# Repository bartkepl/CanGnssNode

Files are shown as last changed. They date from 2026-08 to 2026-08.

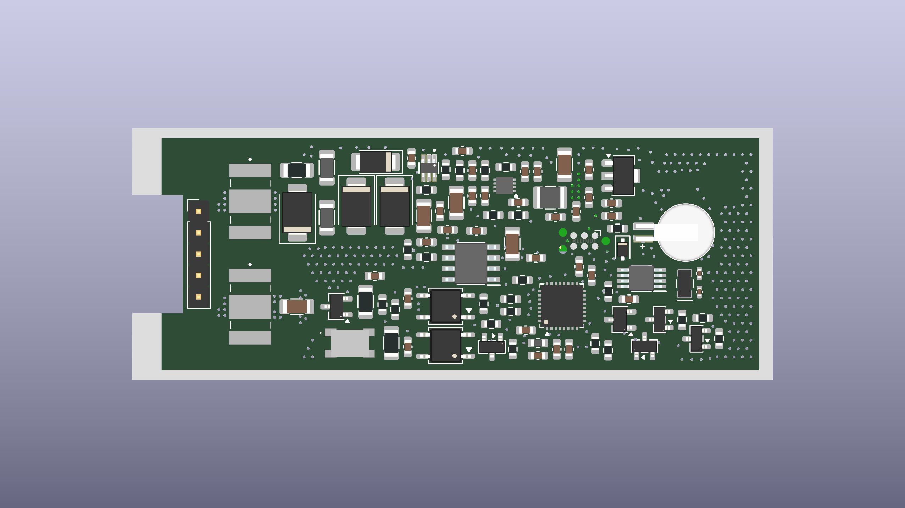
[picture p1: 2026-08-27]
media/gnss_node_front.png

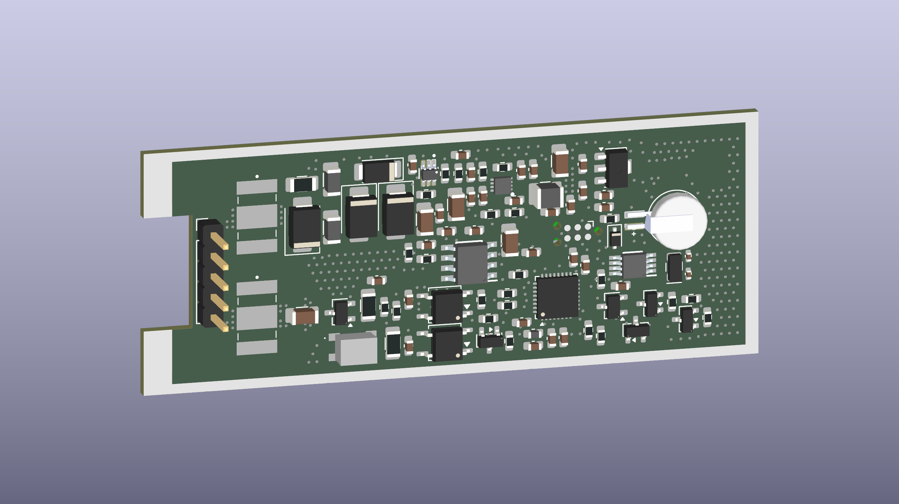
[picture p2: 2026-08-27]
media/gnss_node_angle.png

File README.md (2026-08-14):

# CanGnssNode
## Odbiornik GNSS z interfejsem CAN

Polowy węzeł pozycyjny z modułem GNSS **Quectel L76-L** (GPS/GLONASS/Galileo/QZSS), komunikujący się cyfrowo przez **CAN 2.0B**. Zaprojektowany jako element rozproszonego systemu pomiarowego: wąski cylindryczny węzeł w obudowie aluminiowej, jedno złącze M12, micropower, odporność EMC klasy przemysłowej.







> **Status:** ta sama filozofia konstrukcyjna co u poprzedniej rewizji sprzętu (rura aluminiowa, złącze M12, zasilanie/CAN/RTC bez zmian), ale sonda pomiarowa i obwód wysokiego napięcia zostają zastąpione modułem GNSS. Elektronika (schemat, PCB) jest obecnie przebudowywana w KiCad — patrz [TODO_GPS_CONVERSION.md](TODO_GPS_CONVERSION.md) po aktualny stan prac i listę zmian do wprowadzenia. Firmware na etapie szkieletu bring-up.

---

## Płytka

PCB będzie **mniejsze i dwustronne** względem pierwowzoru: jedna strona elektronika cyfrowa/zasilanie, druga strona w całości zarezerwowana pod tor RF/antenę GNSS — dzięki temu moduł L76-L może leżeć blisko krawędzi płytki, która trafia pod plastikowy insert z anteną (patrz [Mechanika](#mechanika)). Finalne wymiary i layout są w toku (KiCad) — renderów jeszcze nie ma; zostaną wygenerowane jobsetem [gen_media.kicad_jobset](pcb/gen_media.kicad_jobset) po dokończeniu PCB.

---

## Najważniejsze cechy

- **Prosty odbiornik pozycji GNSS** — moduł Quectel L76-L (GPS + GLONASS + Galileo + QZSS, 33 kanały śledzenia), dane NMEA po UART, pozycja wysyłana cyklicznie na CAN.
- **Micropower** — pobór idle rzędu setek µA dzięki buckowi LT8606 (Iq 2.5 µA) i MCU w trybie niskiego poboru (do ustalenia docelowy tryb w firmware — L76-L ma własne tryby Periodic/AlwaysLocate™/Standby/Backup do wykorzystania).
- **CAN 2.0B (29-bit ID)** z wybudzaniem na aktywność magistrali, 125 kbit/s – 1 Mbit/s.
- **Przełączalna terminacja CAN** — split 2×59 Ω + 4.7 nF załączany dwoma PhotoMOS-ami z GPIO (węzeł na końcu linii vs. w środku, bez zwór).
- **Pomiar własnego poboru prądu** — INA186 A4 (G=200) + shunt 0.5 Ω, rozdzielczość ~2 µA/count; diagnostyka linii i weryfikacja budżetu mocy.
- **Zegar czasu rzeczywistego z podtrzymaniem** — MCP79410 + ogniwo MS621FE; kwarc 32.768 kHz służy też do kalibracji wewnętrznego MSI w STM32. Docelowo RTC dostaje korektę z czasu UTC dostarczanego przez GNSS po uzyskaniu fixa.
- **Odporność EMC** — kaskadowa ochrona coarse→fine (GDT 3-elektrodowe / TVS / CMC / podwójne ferryty) na zasilaniu i CAN, testy IEC 61000-4-2/-4/-5.
- **Obudowa aluminiowa IP67**, złącze M12 5-pin A-coded (standard CANopen CiA 303-1).

---

## Specyfikacja

| Parametr | Wartość |
|---|---|
| Moduł GNSS | Quectel L76-L (LCC-18, 10.1×9.7×2.5 mm) |
| Konstelacje | GPS, GLONASS, Galileo (E1), QZSS, SBAS (WAAS/EGNOS/MSAS/GAGAN) |
| Dokładność pozycji | < 2.5 m CEP (autonomicznie) |
| TTFF | ~5 s (warm start, EASY™) |
| Czułość | -167 dBm (tracking) / -149 dBm (acquisition) |
| Wyjście danych | NMEA 0183 po UART, domyślnie 9600 8N1 (opcjonalnie I2C — L76-L ma wyprowadzone I2C_SDA/SCL) |
| Interfejs magistrali | CAN 2.0B (extended ID), 125k / 250k / 500k / 1 Mbit |
| Zasilanie | 7–32 V DC, wspólna masa (bez izolacji galwanicznej) |
| Ochrona EMC | ESD ±8 kV, Burst ±2 kV, Surge ±2 kV |
| Złącze | M12 5-pin A-coded (1=Vin, 2=GND, 3=CAN_H, 4=CAN_L, 5=Earth) |
| PCB | dwustronne, wymiary w trakcie ustalania (KiCad) |
| Obudowa | Aluminiowa cylindryczna, rura **32×1 mm** (Ø wewn. ≈ 30 mm), z uchwytem mocującym; górna część = insert plastikowy z miejscem na antenę GNSS |

---

## Architektura

```
M12 Vin (7-32V) ─▶ Ochrona (GDT+TVS+ferryt) ─▶ shunt 0.5Ω ─▶ LT8606 buck ─▶ +5V ─┬─▶ ATA6561 (CAN)
                                                    │                              │
                                                 INA186 ─▶ ADC                     ├─▶ MCP1700 LDO ─▶ +3.3V ─┬─▶ STM32L432
                                                                                   │                          │
                                                                                   │                MCP79410 RTC + BT1
                                                                                   │                          │
                                                                                   └──────────────────────────┴─▶ Quectel L76-L ─▶ antena GNSS
                                                                                                                          │
                                                                                                    UART (NMEA) ──────────┘
                                                                                                          │
                                                                                                    STM32L432 ─▶ parsowanie ─▶ ramki CAN z pozycją
```

Kluczowa cecha: **wspólna masa** (star ground), izolacja zapewniona wyłącznie przez TVS/GDT; `Earth` (obudowa) oddzielona od `GND` sygnałowej i łączona tylko przez Y-cap 1 nF/2 kV.

### Arkusze schematu

| Arkusz | Plik | Zawartość | Status |
|---|---|---|---|
| root | [gnss_node.kicad_sch](pcb/gnss_node.kicad_sch) | połączenia hierarchiczne | do aktualizacji (patrz TODO) |
| PWR | [pwr.kicad_sch](pcb/pwr.kicad_sch) | buck LT8606, LDO MCP1700, INA186, dzielnik VIN_SENSE | bez zmian — w pełni odziedziczone |
| MCU | [mcu.kicad_sch](pcb/mcu.kicad_sch) | STM32L432, RTC MCP79410, kwarc 32k, SWD (Tag-Connect) | do aktualizacji (piny UART/PPS/RESET do GNSS) |
| GPS | `gps.kicad_sch` (do utworzenia) | moduł Quectel L76-L, antena, VBACKUP | nowy arkusz — patrz TODO |
| CAN_BUS | [can_bus.kicad_sch](pcb/can_bus.kicad_sch) | ATA6561, terminacja PhotoMOS | bez zmian — w pełni odziedziczone |
| PROTECTION | [prot.kicad_sch](pcb/prot.kicad_sch) | ochrona Vin i CAN, złącze M12 | bez zmian — w pełni odziedziczone |
| ~~HV~~ | ~~`hv.kicad_sch`~~ | ~~flyback, dzielnik HV, detektor G-M~~ | **do usunięcia** |

Pełna checklista zmian: [TODO_GPS_CONVERSION.md](TODO_GPS_CONVERSION.md).

---

## Kluczowe komponenty

| Blok | Element | Uwaga |
|---|---|---|
| GNSS | Quectel L76-L | LCC-18, UART NMEA 9600 8N1 (opcjonalnie I2C), VCC 2.8–4.3 V (typ. 3.3 V z istniejącej szyny), V_BCKP z istniejącego BT1 |
| Antena | pasywna lub aktywna GNSS 1575 MHz | pasywna wystarcza przy odległości anteny od modułu < 1 m (nasz przypadek — insert w tej samej rurze); aktywna wymaga zasilania z pinu VDD_RF modułu |
| Buck | LT8606IDC#TRPBF | DFN-8, Iq 2.5 µA (zawsze Burst Mode), Vref FB 0.778 V |
| LDO 3.3 V | MCP1700-3302E/MB | SOT-89, Iq 1.6 µA |
| Current sense | INA186A4IDCKR + 0.5 Ω | 40 V CM, G=200, pin EN — pomiar poboru węzła |
| MCU | STM32L432KCU6 | bxCAN, USART2 (GNSS), I2C1 (RTC) |
| RTC | MCP79410-I/MS + MS621FE-FL11E | RTC/EEPROM I2C z podtrzymaniem, kwarc 32.768 kHz |
| CAN | ATA6561-GAQW-N | zamiennik TJA1042 |
| Terminacja CAN | 2× GAQY212GS + 2× 59 Ω + 4.7 nF | split przełączalny, sterowany BSS138 |
| Ochrona Vin | 3R090-5S (GDT) + SMBJ33CA + PMEG6030EP + 2× SMBJ36A | kaskada coarse→fine, podwójny ferryt BLM31 |
| Ochrona CAN | 3R090-5S + CDSOT23-T24CAN + ACT45B-510 | GDT, dedykowany TVS, CMC |

Pełna lista: `prod/bom/` (generowana z KiCad, nietrackowana w git, do wygenerowania po dokończeniu schematu/PCB).

---

## Ramki CAN — szkic protokołu v1

Firmware jest na etapie szkieletu (peryferia zainicjalizowane, brak logiki aplikacji), więc poniższy format to **zamierzenie do implementacji**, nie działający kod. Trzy ramki standardowe (8 B danych), wysyłane cyklicznie po uzyskaniu fixa:

| Ramka | Zawartość (bajty) |
|---|---|
| `POSITION` | szerokość geogr. (int32, 1e-7°) · długość geogr. (int32, 1e-7°) |
| `ALT_SPEED` | wysokość n.p.m. (int32, mm) · prędkość (uint16, 0.01 m/s) · kurs (uint16, 0.01°) |
| `STATUS_TIME` | czas UTC (uint32, epoch) · jakość fixa (uint8) · liczba satelitów (uint8) · HDOP (uint16, 0.01) |

Identyfikatory CAN, dokładna semantyka pól i częstotliwość nadawania do ustalenia razem z resztą firmware (Faza 4 poniżej).

---

## Mechanika

**Rura aluminiowa 32×1 mm** (Ø wewn. ≈ 30 mm) z uchwytem mocującym, IP67 — ta sama koncepcja montażu co u poprzedniej rewizji sprzętu. Różnica: zamiast górnej części z sondą pomiarową — **plastikowy insert z miejscem na antenę GNSS**, bo aluminium ekranuje sygnał satelitarny i antena musi „widzieć” niebo przez materiał nieprzewodzący. PCB (dwustronne, strona RF skierowana pod insert) oraz szczegóły osadzenia anteny (na płytce vs. pigtail do anteny patch w insercie) są przedmiotem trwającej przebudowy w KiCad.

---

## Firmware

Projekt STM32CubeIDE w [firmware/CanGnssNode/](firmware/CanGnssNode/) — na razie szkielet wygenerowany z CubeMX z inicjalizacją CAN1 i I2C1. Peryferia po dawnej sondzie pomiarowej (ADC HV_meas, COMP1, DAC1, TIM2) czekają na usunięcie, a USART2 do modułu GNSS na dodanie — pełna lista zmian w `.ioc` w [TODO_GPS_CONVERSION.md](TODO_GPS_CONVERSION.md). Logika aplikacji (parsowanie NMEA, budowa i nadawanie ramek CAN) do napisania.

---

## Roadmap

- [x] **Faza 1** — wydzielenie nowego sub-projektu, dobór modułu GNSS (Quectel L76-L), dokumentacja zamierzenia
- [ ] **Faza 2** — przebudowa schematu w KiCad: nowy arkusz GPS, usunięcie arkusza HV, aktualizacja pinów MCU (patrz TODO)
- [ ] **Faza 3** — przebudowa PCB (dwustronne, sekcja RF), pliki produkcyjne
- [ ] **Faza 3b** — zamówienie PCB, montaż, bring-up sprzętowy
- [ ] **Faza 4** — firmware (parser NMEA, protokół CAN z pozycją, synchronizacja RTC z czasem GNSS, tryby oszczędzania energii L76-L)
- [ ] **Faza 5** — testy terenowe (dokładność pozycji, TTFF, zasięg anteny w obudowie), testy EMC
- [ ] **Faza 6** — mechanika: rura Al 32×1 mm, plastikowy insert z anteną, testy IP67

---

## Struktura repozytorium

```
.
├── media/          # rendery 3D płytki (do wygenerowania po nowym PCB)
├── pcb/            # projekt KiCad 10 (schemat hierarchiczny, PCB, biblioteki lokalne, modele 3D)
├── prod/           # pliki produkcyjne: gerbery (.zip), PDF schematu i PCB, interaktywny BOM (do wygenerowania po nowym PCB)
├── sim/            # symulacje LTspice (LT8606 buck)
└── firmware/       # projekt STM32CubeIDE (STM32L432, szkielet bring-up)
```

Pliki produkcyjne generowane są jobsetami KiCad: [gen_prod.kicad_jobset](pcb/gen_prod.kicad_jobset) (PDF + BOM), [gen_gerber.kicad_jobset](pcb/gen_gerber.kicad_jobset) (gerbery + wiertła), [gen_media.kicad_jobset](pcb/gen_media.kicad_jobset) (rendery 3D).

---

## Referencje

- Quectel **L76 & L76-L Hardware Design** (GNSS Module Series), v3.2 — pinout, elektryka, projekt anteny
- NMEA 0183 — format komunikatów wyjściowych GNSS
- STM32L432: RM0394, DS11453; bxCAN: AN2606, AN5028
- LT8606 (Analog Devices), MCP1700 / MCP79410 / ATA6561 (Microchip)
- IEC 61000-4-2/-4/-5; EN 61326-1; EN 61000-6-2
- CAN 2.0B: ISO 11898-1/-2; CANopen CiA 301, CiA 303-1; M12: IEC 61076-2-101

---

## Licencja

MIT

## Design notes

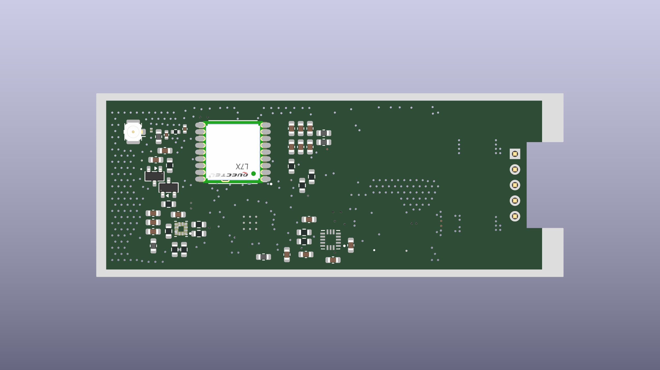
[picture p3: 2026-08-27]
media/gnss_node_back.png

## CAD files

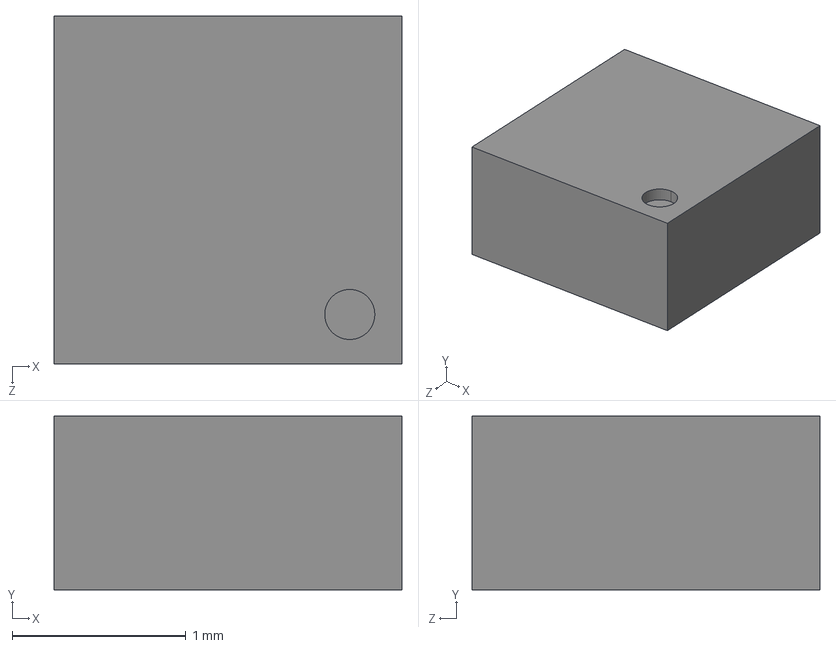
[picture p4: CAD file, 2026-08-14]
pcb/lib_local/LSM303AGR.step
2.00 x 1.00 x 2.00 mm

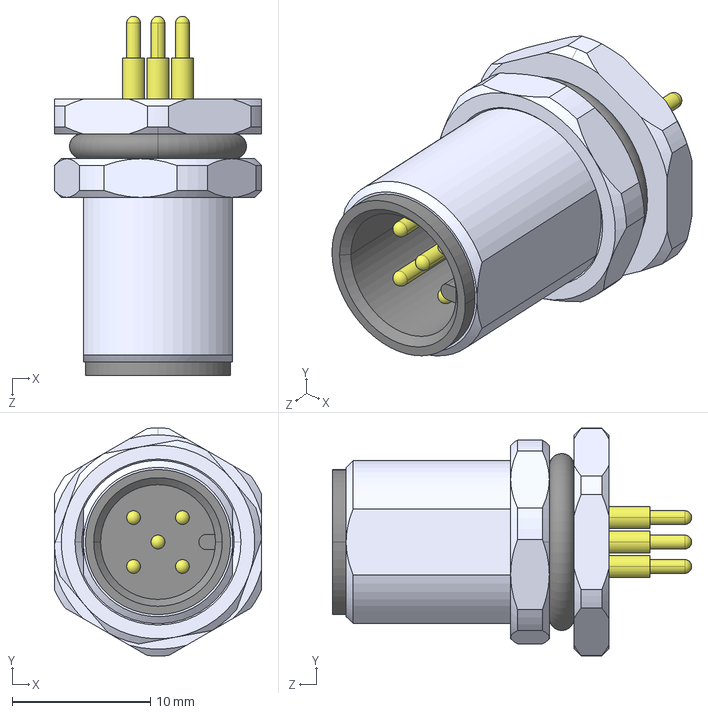
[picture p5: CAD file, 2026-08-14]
pcb/lib_local/CDM1209-05A-MP-F12-67.step
15.0 x 16.5 x 26.0 mm
CDM1209 HOUSING
PINS_MALE_REAR_5P

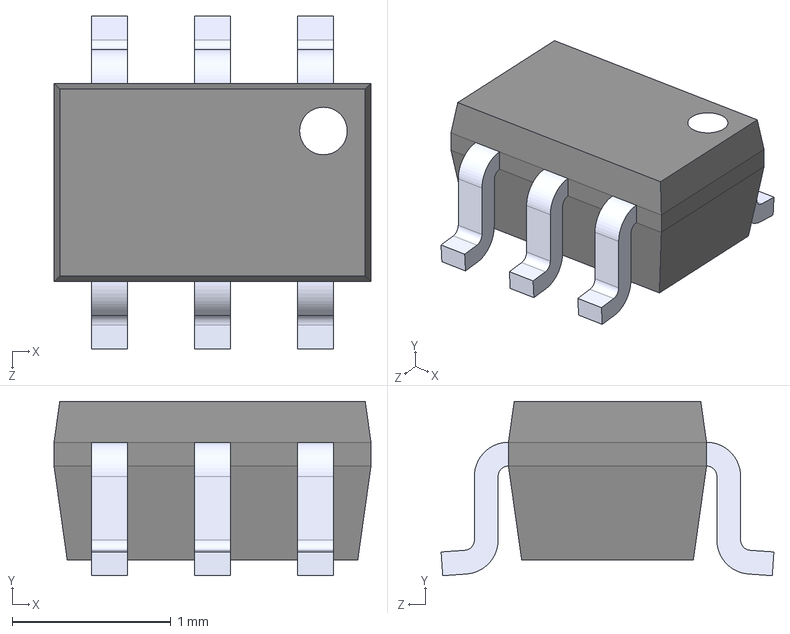
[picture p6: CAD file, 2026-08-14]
pcb/lib_local/INA186A4IDCKR.step
2.00 x 1.10 x 2.10 mm

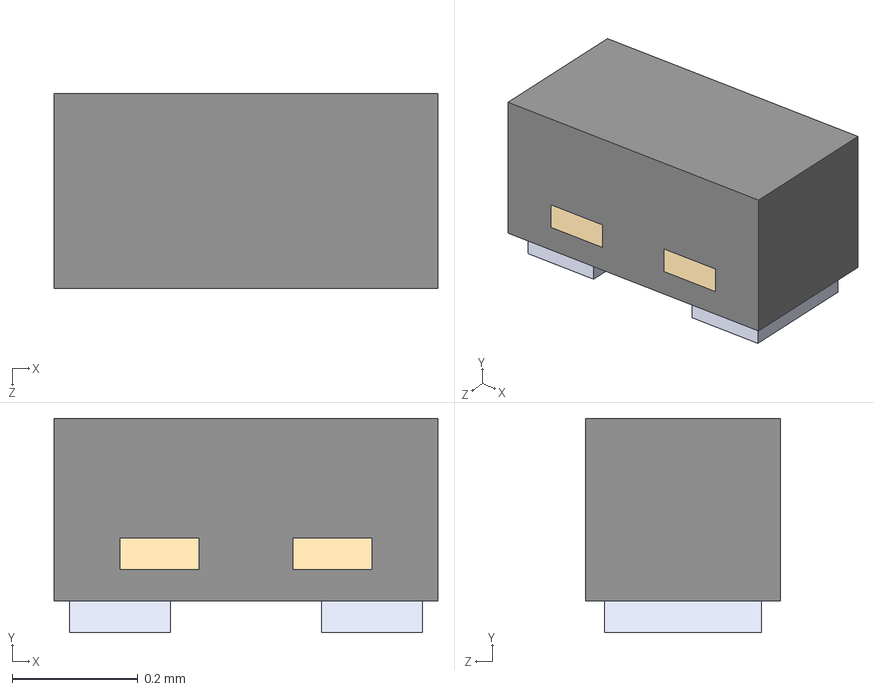
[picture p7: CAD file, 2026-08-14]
pcb/lib_local/DFN0603.step
0.61 x 0.34 x 0.31 mm

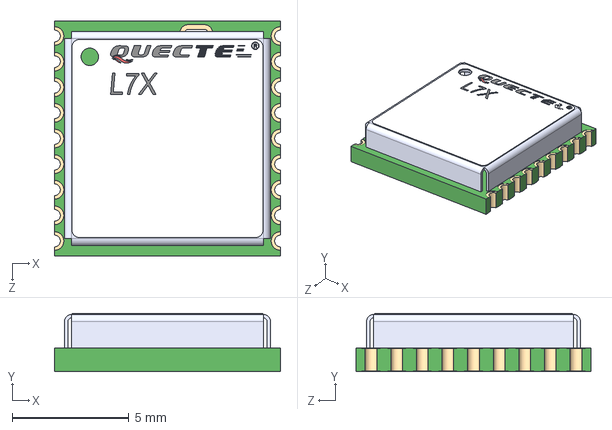
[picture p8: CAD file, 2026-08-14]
pcb/lib_local/L76L-M33.step
9.70 x 2.49 x 10.1 mm

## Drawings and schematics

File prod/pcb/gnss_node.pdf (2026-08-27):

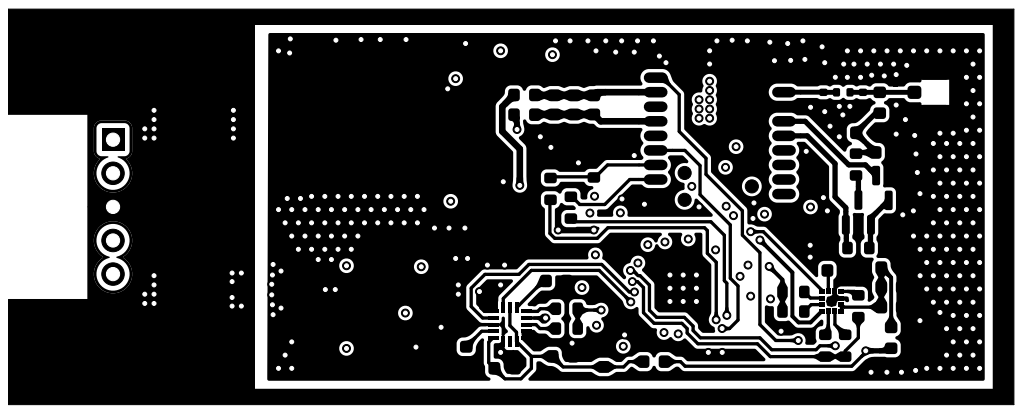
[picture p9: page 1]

Size: A4 | Rev:
KiCad E.D.A. 10.0.4 | Id: 1/6

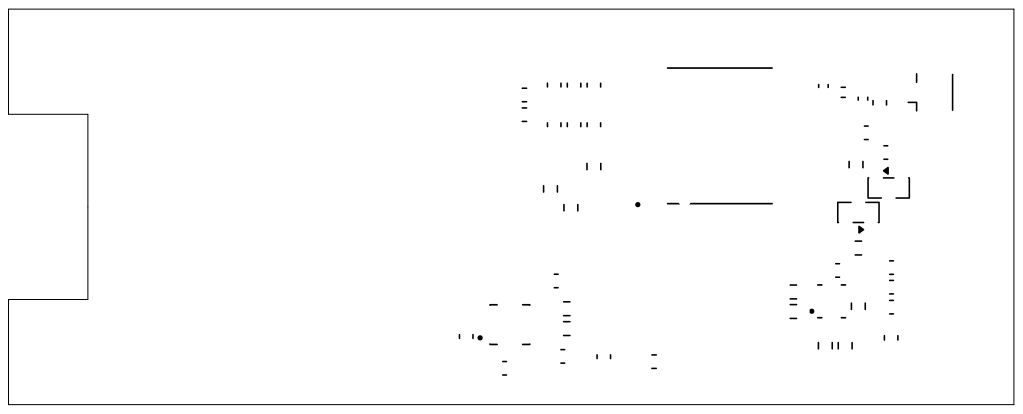
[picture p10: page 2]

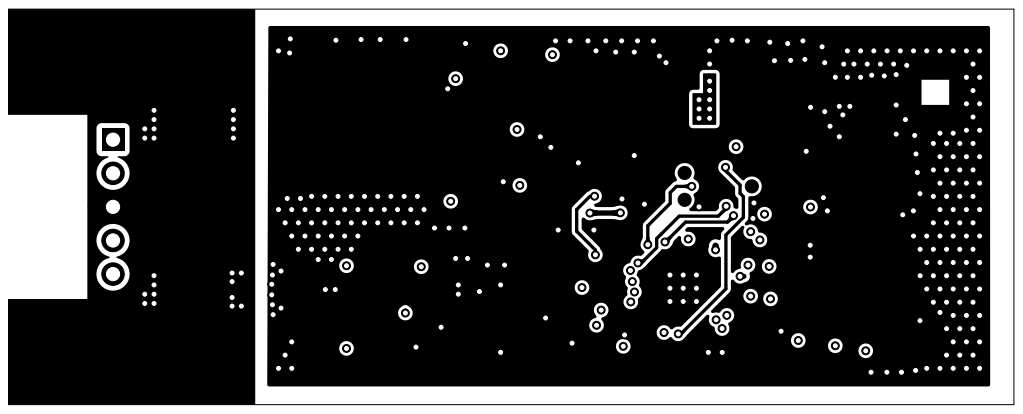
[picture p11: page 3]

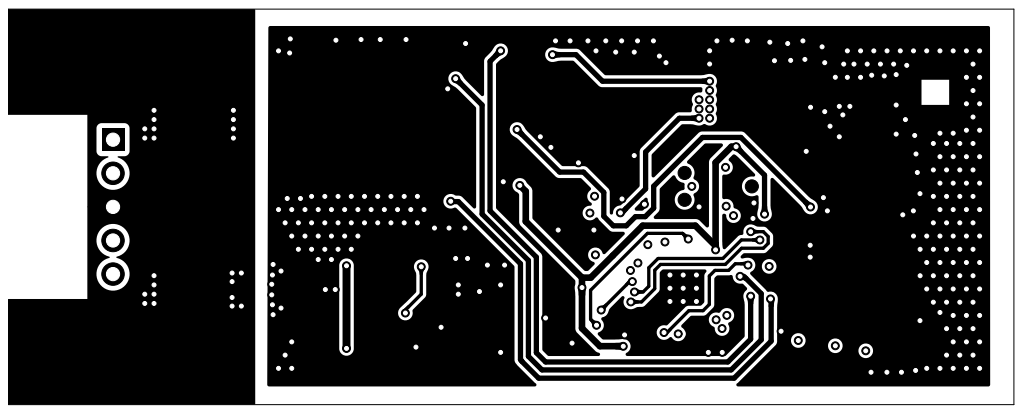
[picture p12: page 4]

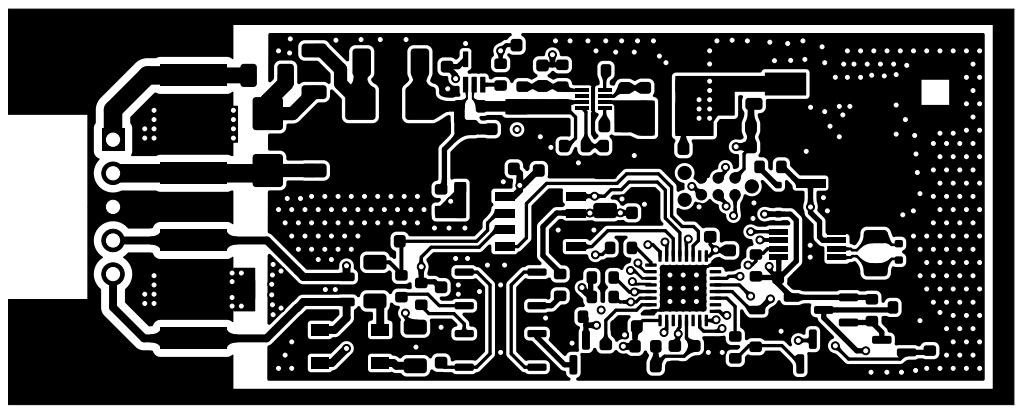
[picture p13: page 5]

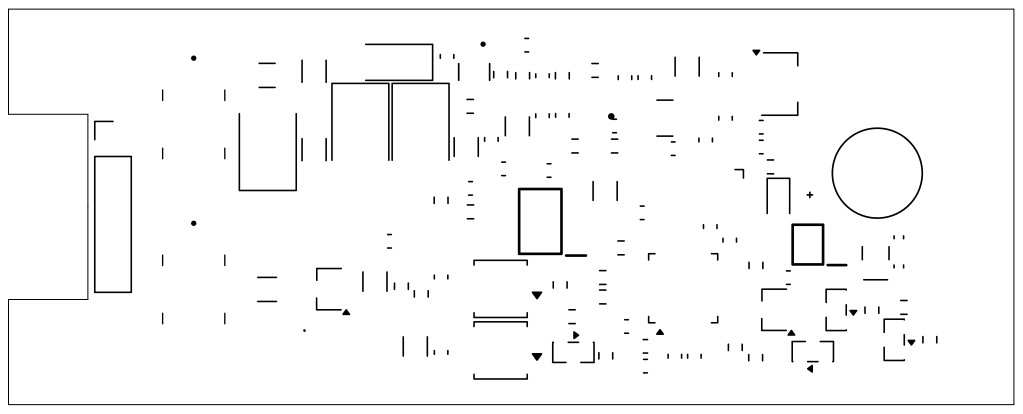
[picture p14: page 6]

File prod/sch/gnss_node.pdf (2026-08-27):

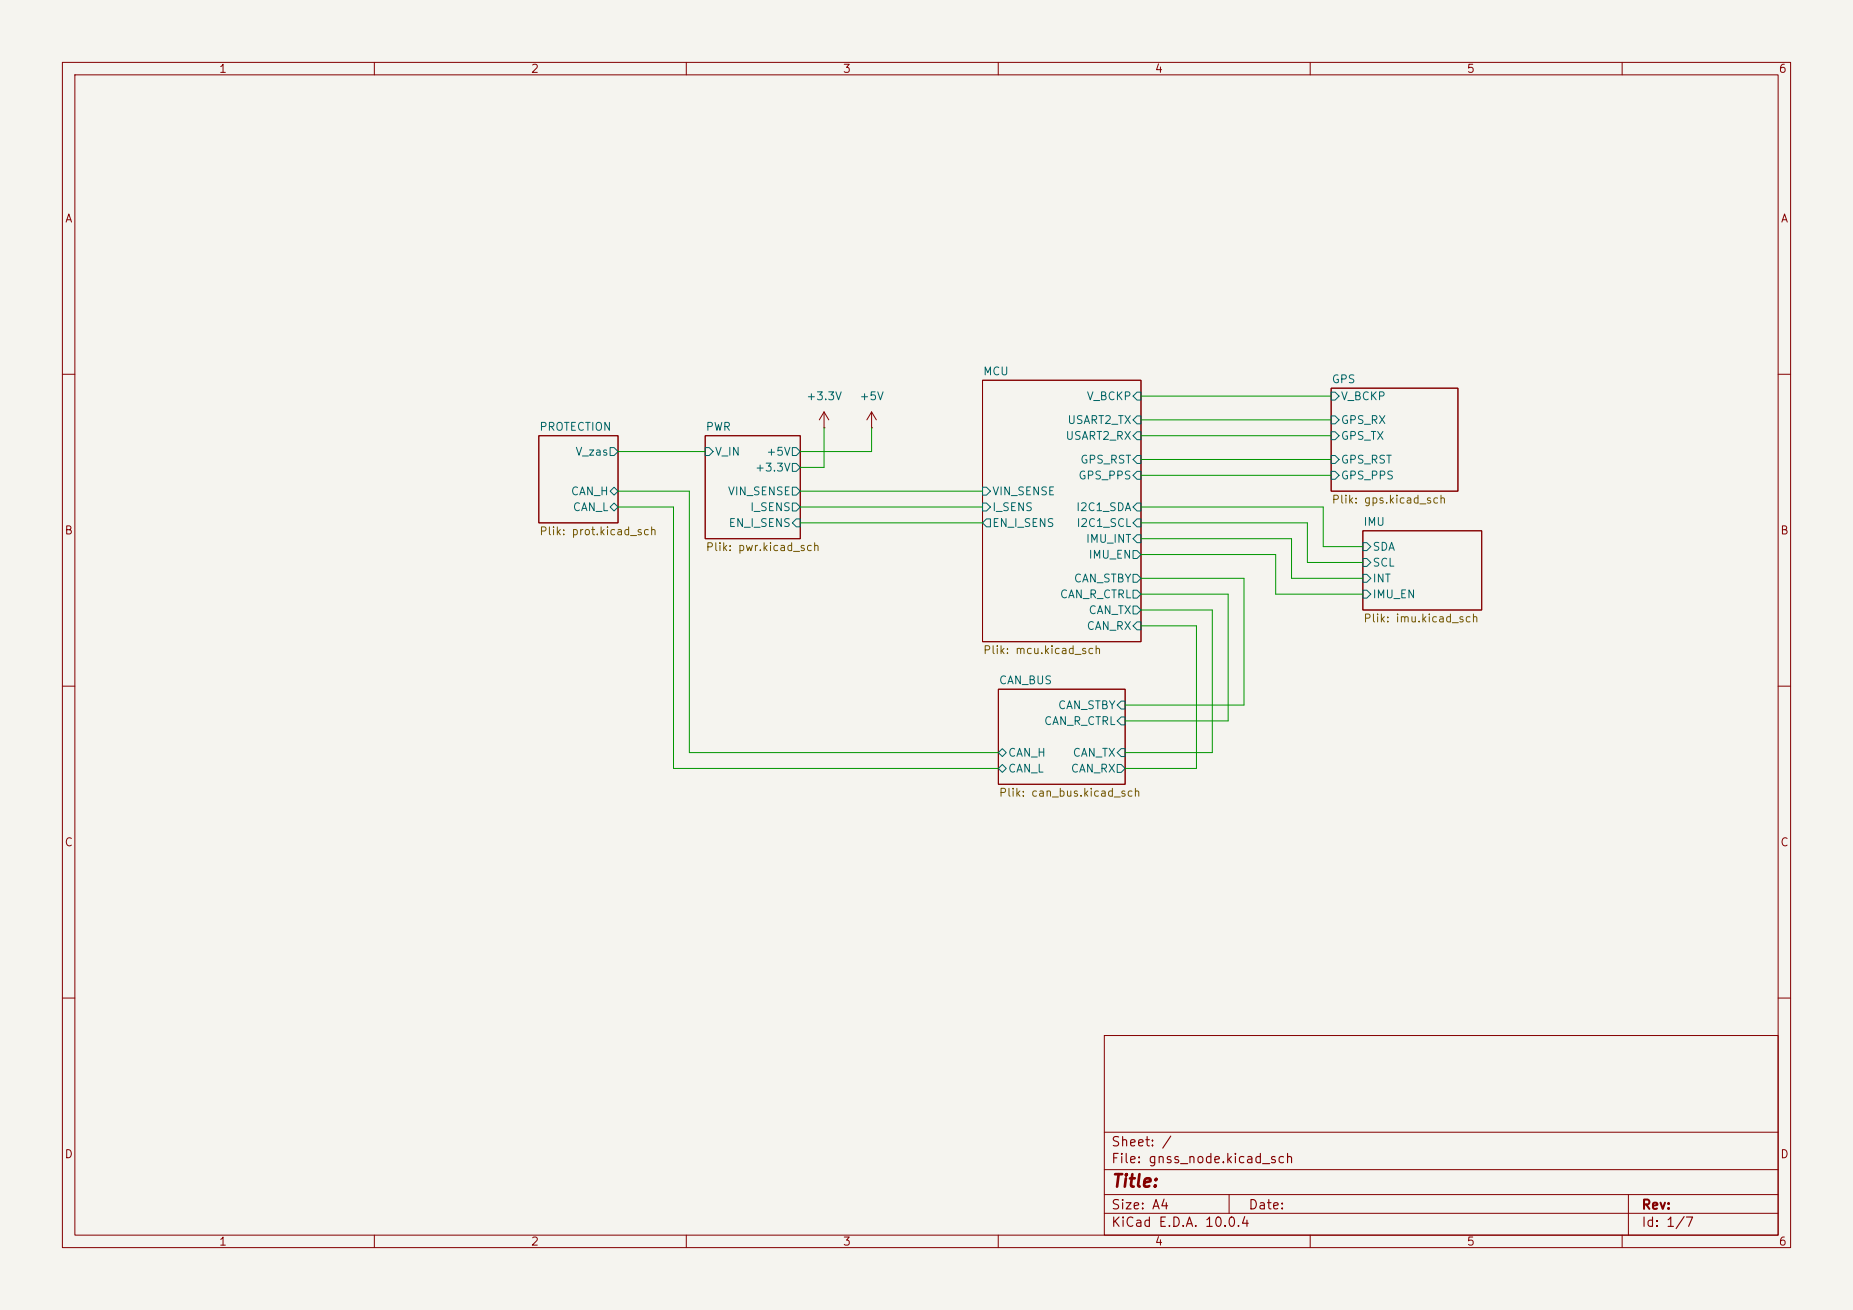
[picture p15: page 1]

Size: A4 | Rev:
KiCad E.D.A. 10.0.4 | Id: 1/7

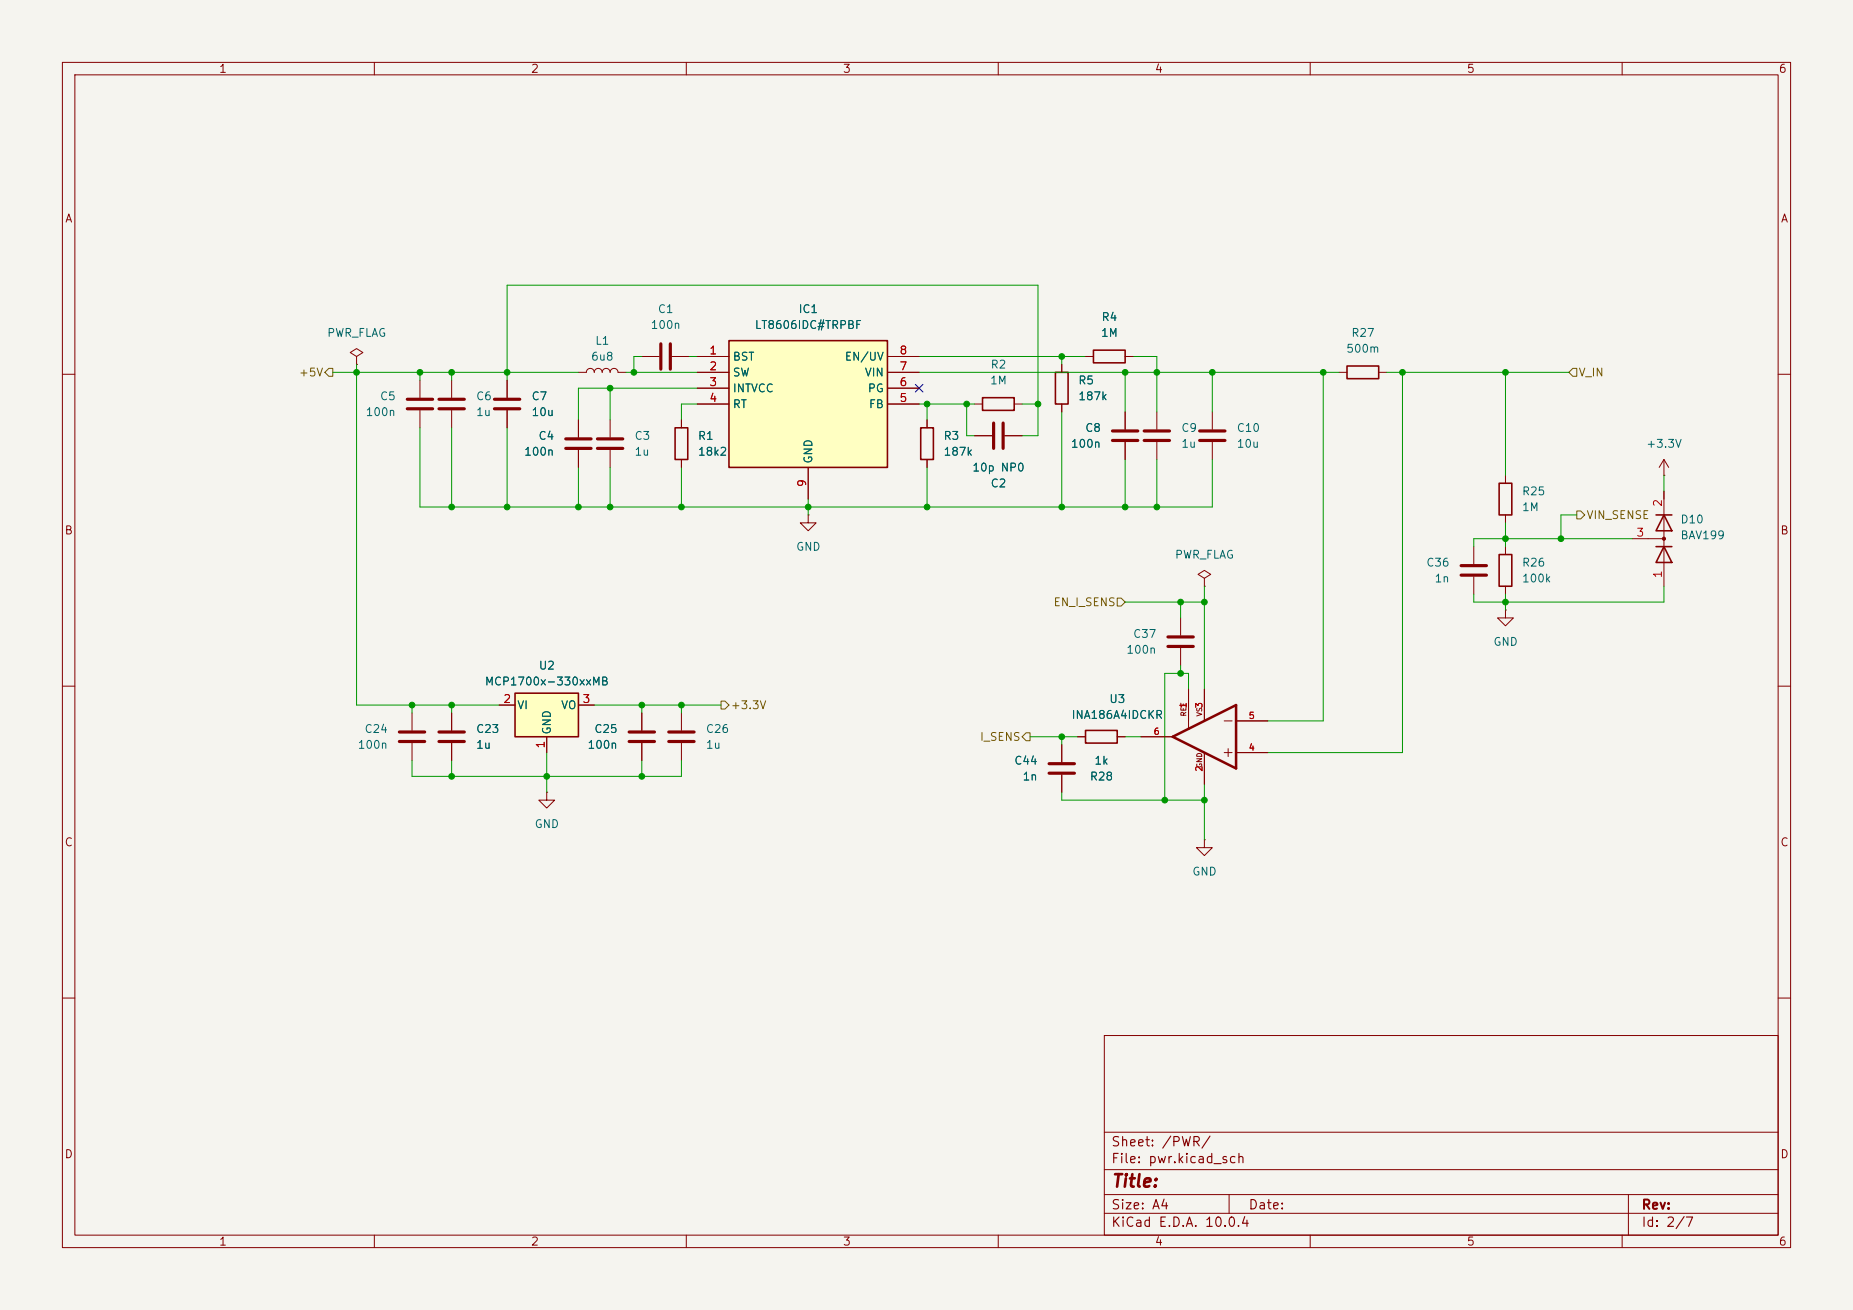
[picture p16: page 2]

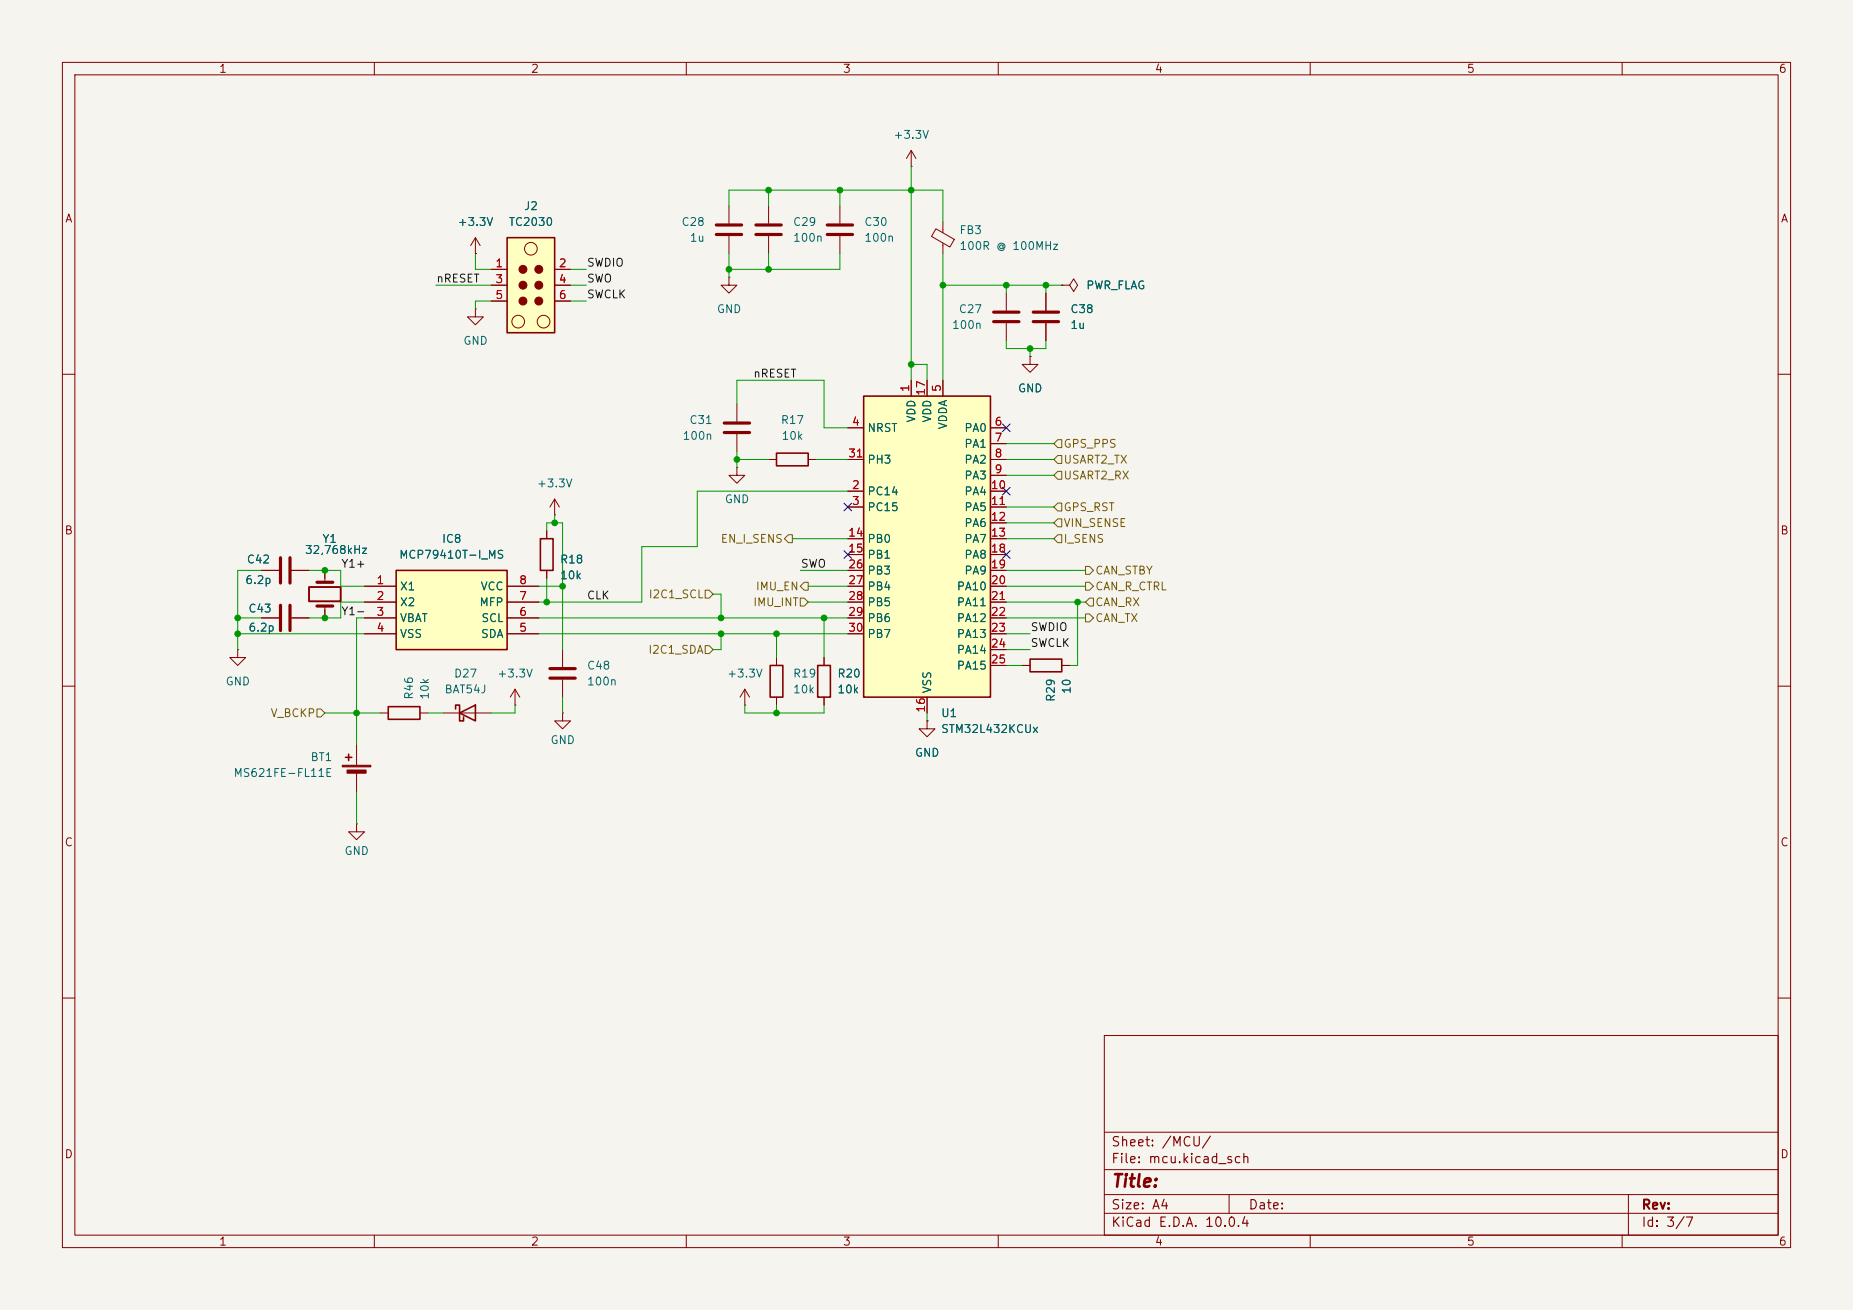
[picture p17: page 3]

1 PC14 2 PC15 3 NRST 4 VDDA 5 PA0 6 PA1 7 PA2 8 PA3 9 PA4 10 PA5 11 PA6 12 PA7 13 PB0 14 PB1 15 VSS 16 VDD 17 PA8 18 PA9 19 PA10 20 PA11 21 PA12 22 PA13 23 PA14 24 PA15 25 PB3 26 PB4 27 PB5 28 PB6 29 PB7 30 PH3 31 R20

1 PC14 2 PC15 3 NRST 4 VDDA 5 PA0 6 PA1 7 PA2 8 PA3 9 PA4 10 PA5 11 PA6 12 PA7 13 PB0 14 PB1 15 VSS 16 VDD 17 PA8 18 PA9 19 PA10 20 PA11 21 PA12 22 PA13 23 PA14 24 PA15 25 PB3 26 PB4 27 PB5 28 PB6 29 PB7 30 PH3 31 U1

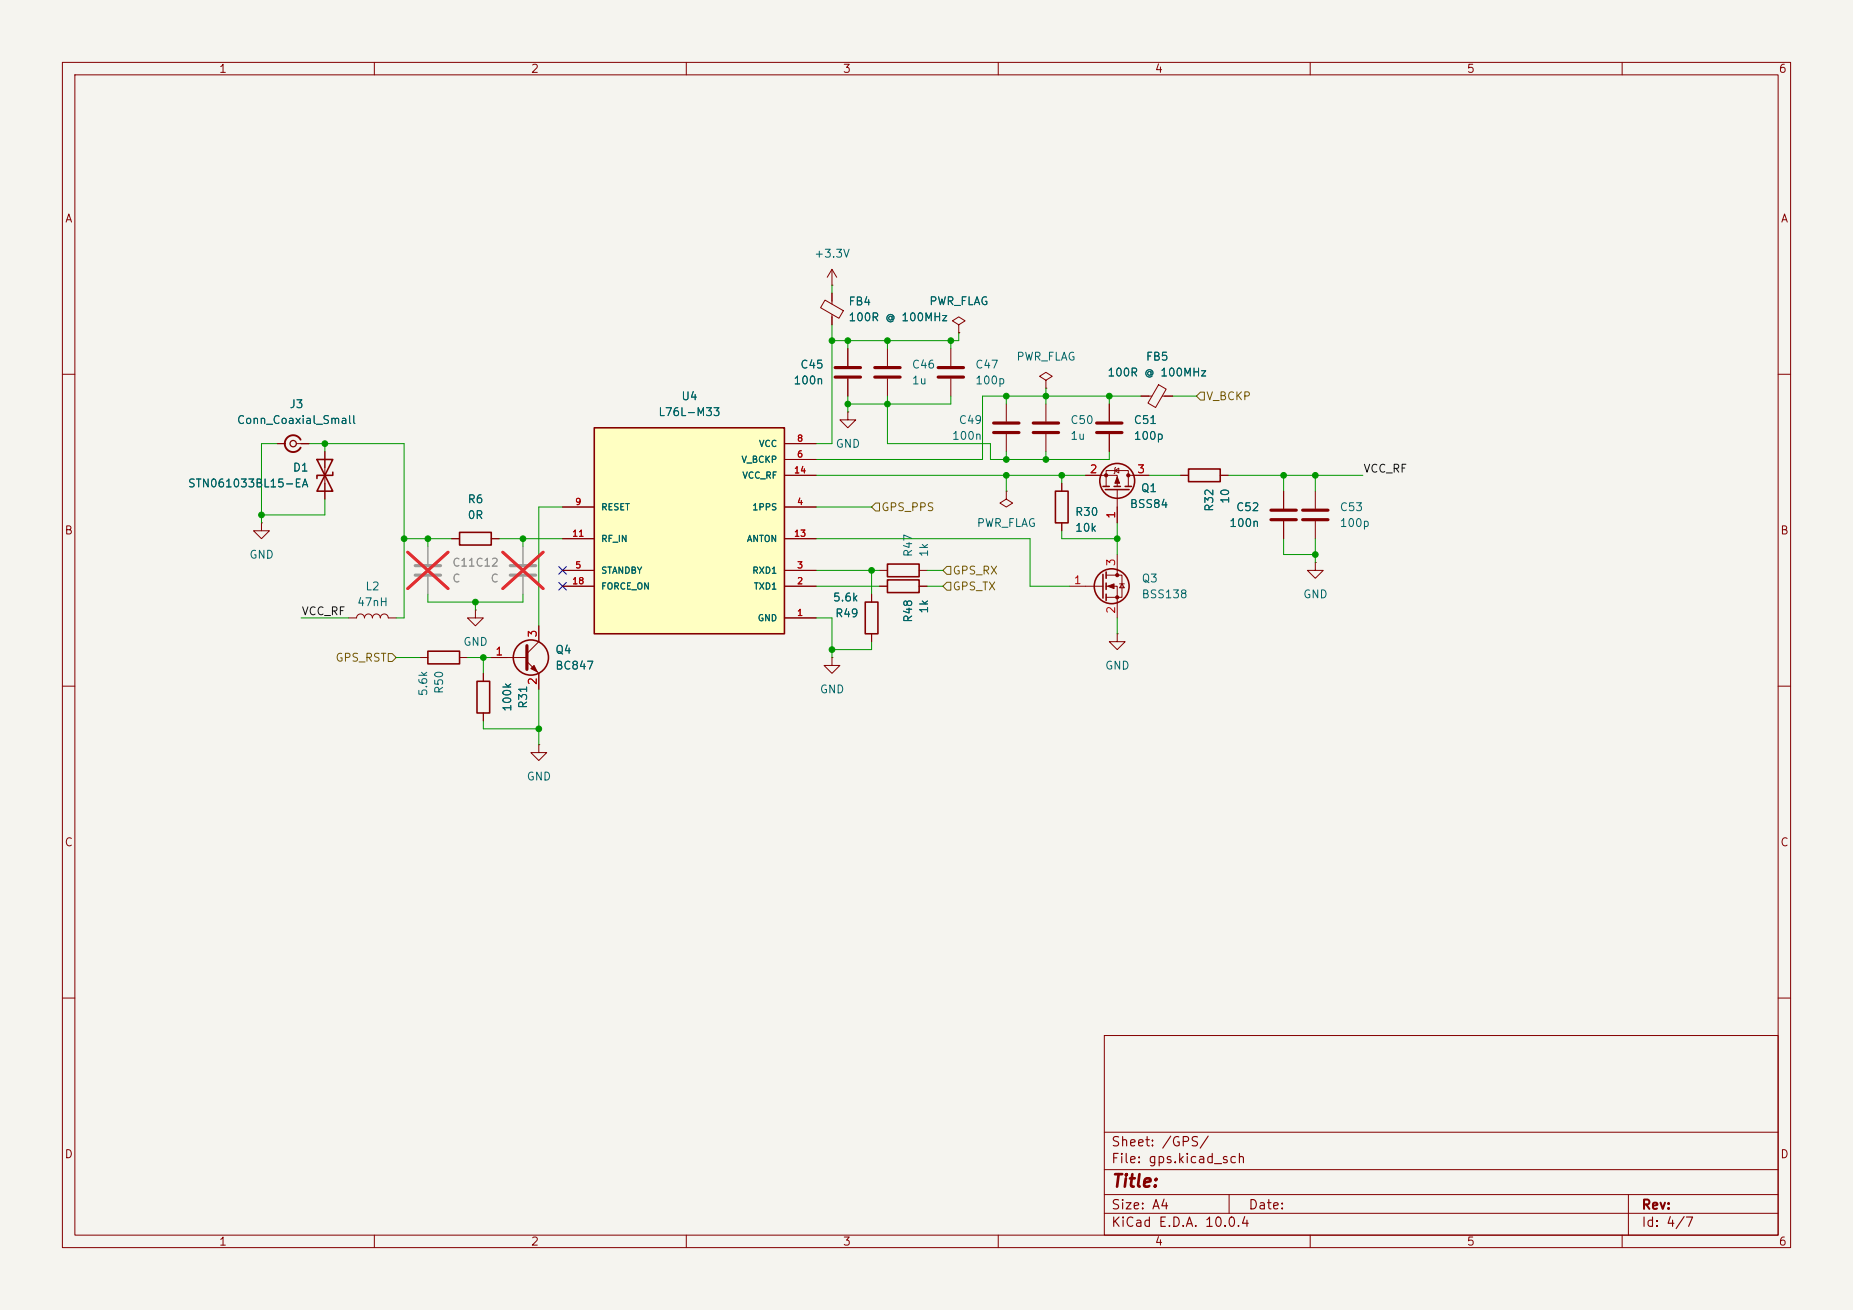
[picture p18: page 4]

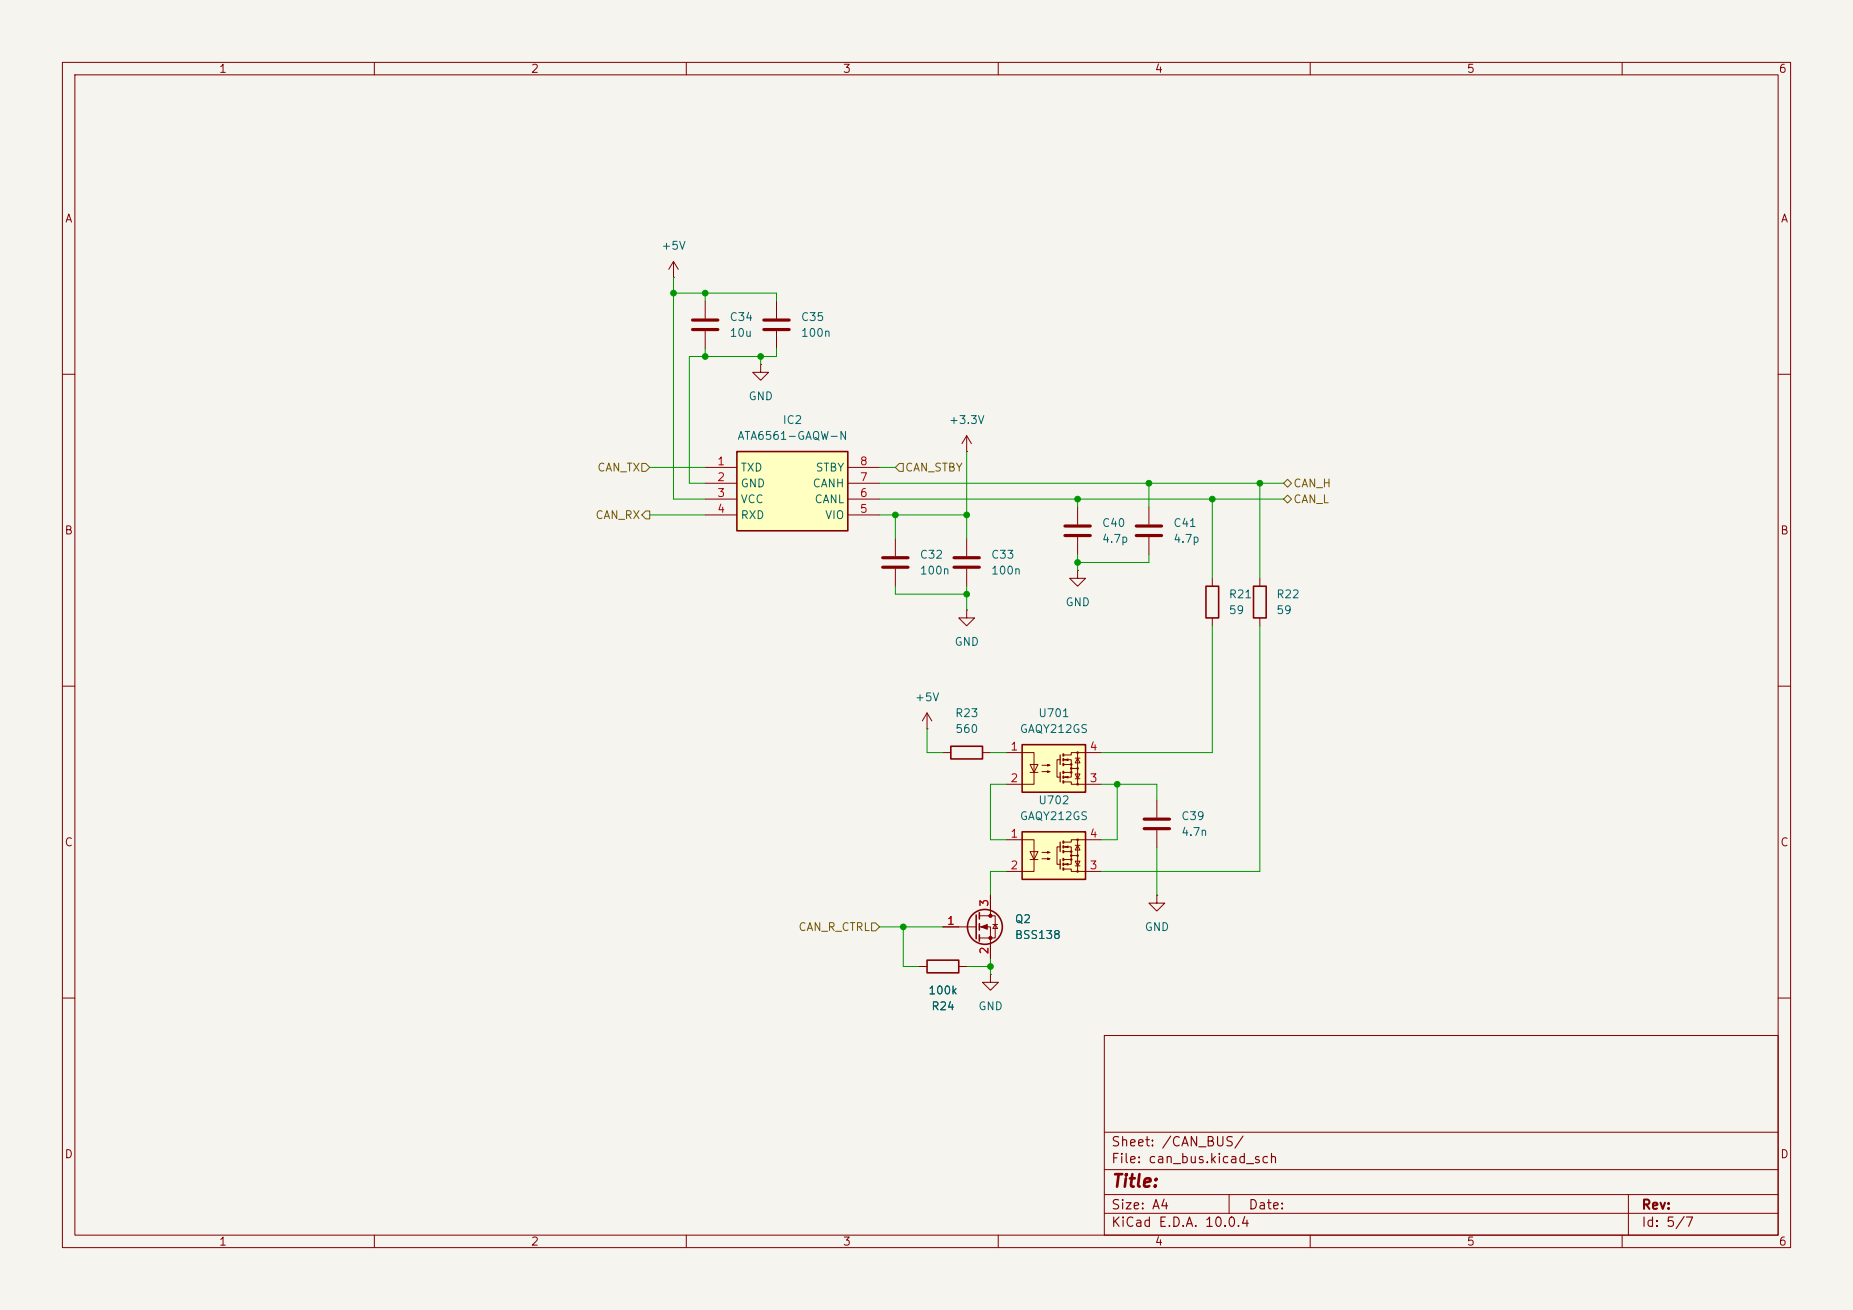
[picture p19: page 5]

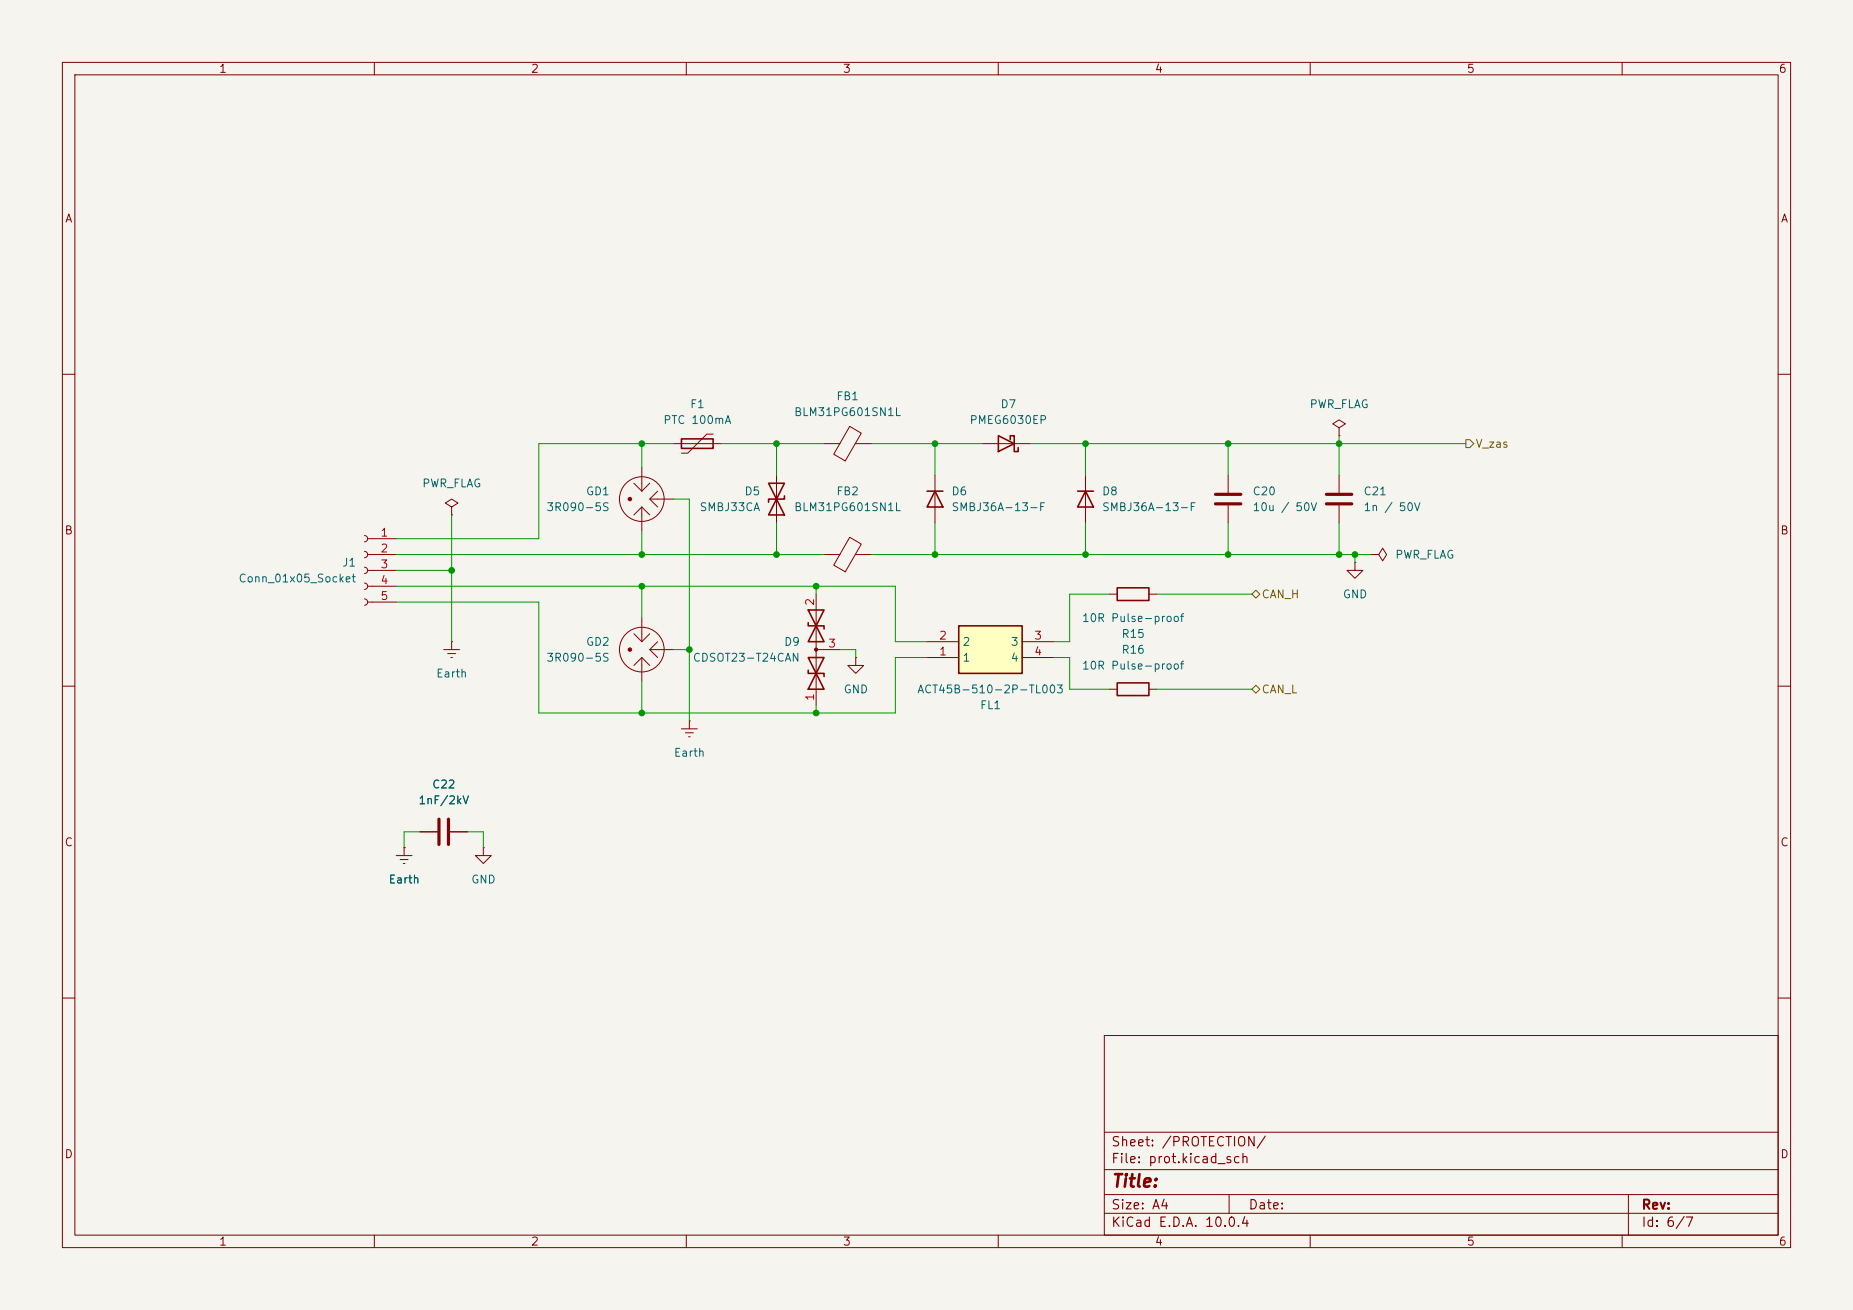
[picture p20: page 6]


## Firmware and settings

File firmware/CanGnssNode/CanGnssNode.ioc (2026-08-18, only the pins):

Mcu.UserName=STM32L432KCUx
PA1.GPIO_Label=GPS_PPS
PA1.Signal=GPIO_Output
PA10.GPIO_Label=CAN_R_CTRL
PA10.Signal=GPIO_Output
PA11.Signal=CAN1_RX
PA12.Signal=CAN1_TX
PA2.Signal=USART2_TX
PA3.Signal=USART2_RX
PA5.GPIO_Label=GPS_RESET
PA5.Signal=GPIO_Output
PA6.GPIO_Label=VIN_SENSE
PA6.Signal=ADCx_IN11
PA7.GPIO_Label=I_SENS
PA7.Signal=ADCx_IN12
PA9.GPIO_Label=CAN_STBY
PA9.Signal=GPIO_Output
PB0.GPIO_Label=EN_I_SENS
PB0.Signal=GPIO_Output
PB5.GPIO_Label=IMU_EN
PB5.Signal=GPIO_Output
PB6.Signal=I2C1_SCL
PB7.Signal=I2C1_SDA

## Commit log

2026-08-14 Schematic done, routing todo
    [CDM1209-05A-MP-F12-67.step, DFN0603.step, INA186A4IDCKR.step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]
2026-08-14 More schematic
    [LSM303AGR.step, gnss_node.kicad_pcb, gnss_node.kicad_sch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]
2026-08-18 finnishing touches
    [gnss_node.kicad_pcb, gps.kicad_sch, imu.kicad_sch]
2026-08-21 DRC fixes
    [gnss_node.kicad_pcb]
2026-08-27 Unify passive values/footprints, add via-in-pad DRC rule, regen prod outputs
    [can_bus.kicad_sch, gnss_node.kicad_pcb, gps.kicad_sch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]
2026-09-25 Add fiducials, update README for production state, regenerate outputs
    - 2 fiducials per side
    - Remove orphaned HV_lines netclass (matched no nets since HV sheet removal)
    - README: production-ready status, 3D renders, GPS/IMU sheets, corrected power
    budget note (GNSS receiver dominates, no longer "hundreds of uA idle"),
    links to PDFs and interactive BOM, dead TODO_GPS_CONVERSION.md links removed
    - Add interactive BOM (prod/ibom), regenerate PDFs, gerber zip and 3D renders
2026-11-08 lib_local: SMT nut M2 footprint (Sinhoo SMTSO2005CTJ / SMTSO2010CTJ, PEM SMTSO compatible, plated ring both sides) + 3D models H0.5 / H1.0
2026-11-08 M12 connector: SMT M2 nuts H1/H2 (Sinhoo SMTSO, lib_local footprint) on Earth; regenerate gerbers (zip), PDFs and renders
2026-11-08 BOM fields: MPN / Manufacturer / LCSC / TME / Mouser from Big_order_2026 rev.2 order (unified part numbers), old sourcing fields (Manufacturer_Part_Number, MF, MP, Mouser/Arrow/TME price fields, Snap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
2026-11-08 PCB updated from schematic (F8: MPN/LCSC/TME/Mouser fields); regenerate gerber zip, iBOM (MPN/LCSC/TME/Mouser columns), BOM and PDFs
